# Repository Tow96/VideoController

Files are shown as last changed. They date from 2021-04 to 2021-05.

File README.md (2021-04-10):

# Video Controller Surface



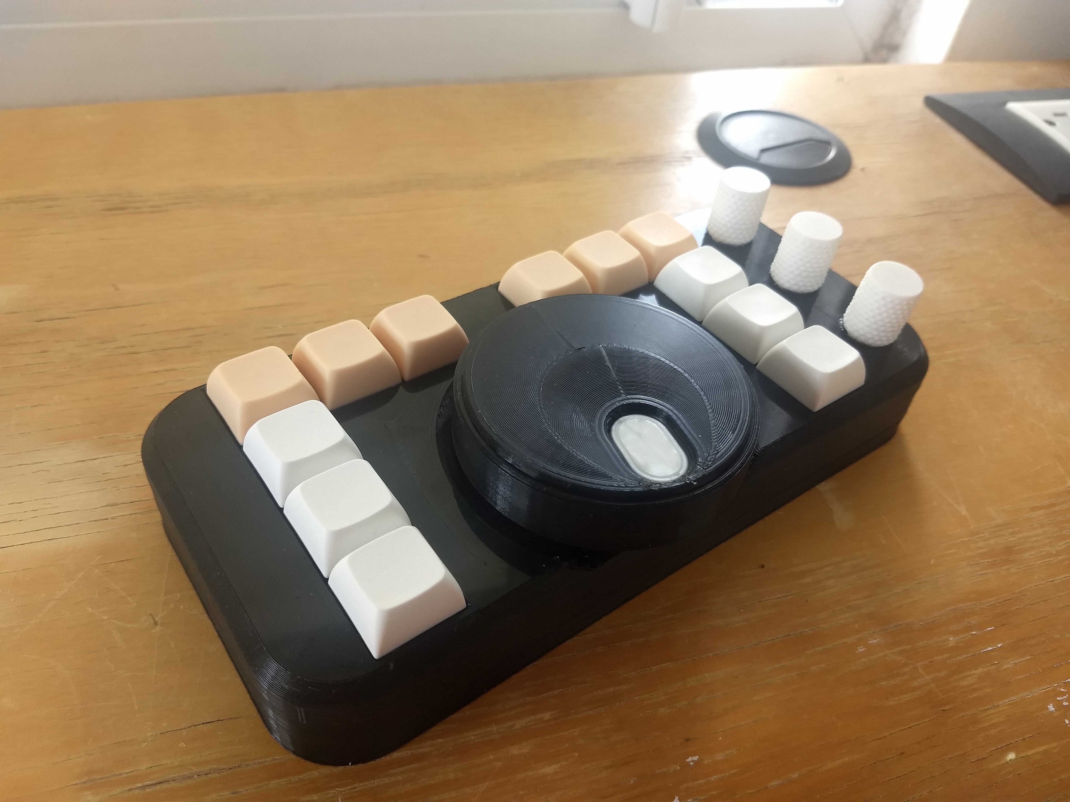
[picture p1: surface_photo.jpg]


Simple surface for video editing utilizing a Teensy 2.0 It's main purpose is to be utilized with the program 
Adobe Premiere Pro. However, thanks to the Teensy's HID interface, can also be utilized as a multipurpose 
Macro pad.

This surface has 12 buttons, a main central knob, and 3 secondary knobs. The four knobs also have buttons.

This project is heavily based by Zack-Freedman's [Big-Wheel](https://github.com/ZackFreedman/Big-Wheel) 
project.

## Repository structure
The repository is divided in four subfolders, each containing a different part of the project. Further 
documentation can be found inside these folders.

1. [**Assembly**](/Assembly) - This folder contains the files that make up the physical device. They are 
available in .SLDPRT and .STL formats.

2. [**Firmware**](/Firmware) - This folder contains the Firmware utilized by the device. It is built in 
platform.io and uses the [Teensyduino](https://www.pjrc.com/teensy/td_download.html) library.

3. [**Schematics**](/Schematics) - This folder contains the wiring diagrams, as well as the elements to 
manufacture a PCB for it.

4. [**Shortcut-Profiles**](/Shortcut-Profiles) - This folder contains .kys files for Adobe Premiere.

## Future improvements
The improvements are separated by category inside the documentation for each folder.

## Credits
- Jose Tow [[@Tow96](https://github.com/Tow96)]

Original idea from: Zack Freedman ([github](https://github.com/ZackFreedman), 
[youtube](https://www.youtube.com/channel/UCUW49KGPezggFi0PGyDvcvg))

## License
This project is licensed under [MIT license](/LICENSE) as I believe in open-source, specially when basing 
your project from another.

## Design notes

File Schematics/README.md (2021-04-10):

# Schematics
This folder contains the wiring diagrams, as well as the elements to manufacture a PCB for it.

The files are in EAGLE CAD format and also the gbr files are available to manufacture a PCB out of it.

**Warning:** The PCB has tolerances to fit inside the body of the device, and test prints have 
been made to check if the components fit. However a proper PCB hasn't been manufatured to test

## Teensy pins
The pins to which each component is wired can be changed on the [pins.h](../Firmware/src/pins.h) 
file. The default connections are:

Wire      | Pin
--------- | ---
Row A     | 5
Row B     | 6
Row C     | 16
Row D     | 15
Col 1     | 17
Col 2     | 18
Col 3     | 3
Col 4     | 4
TopKnob A | 8
TopKnob B | 7
MidKnob A | 10
MidKnob B | 9
BotKnob A | 13
BotKnob B | 14
Wheel A   | 11
Wheel B   | 12

## Hand soldering
The case is also designed to be hand soldered instead of using a pcb. Here is the name of each button and knob matching the schematics.

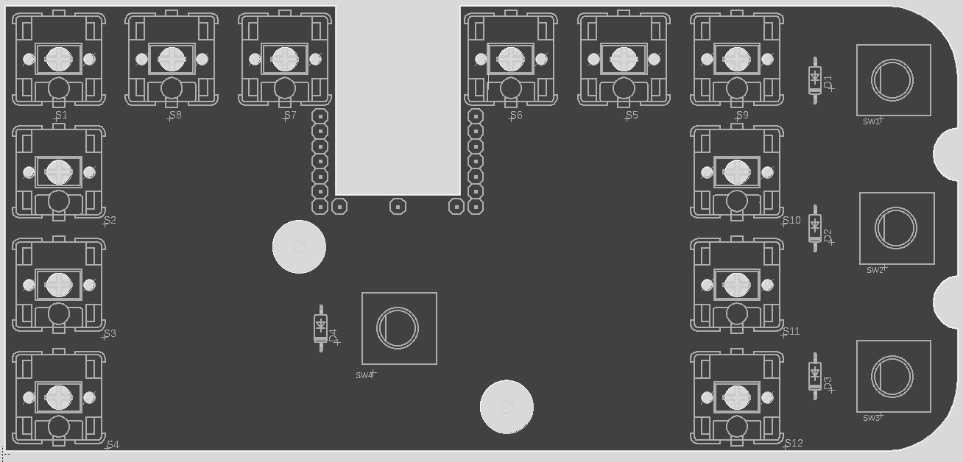
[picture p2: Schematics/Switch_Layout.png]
Layout


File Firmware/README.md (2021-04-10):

# Firmware
This folder contains the Firmware utilized by the device. It is built in 
platform.io and uses the [Teensyduino](https://www.pjrc.com/teensy/td_download.html) library.

## Build
To build the firmware, VsCode with platform.io is required. Building the firmware should 
install the required dependencies.

## Future improvements
- [ ] Add different actions depending of the speed the main knob is turned.

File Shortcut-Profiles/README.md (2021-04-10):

# Shortcut Profiles
This folder contains .kys files for Adobe Premiere. 

The reason for this is that the Teensy keyboard library utilizes the keys for the US keyboard instead of 
ASCII. The issue also applies in Adobe Premiere where depending on the layout of the keyboard, the mappings 
are changed. In order to combat this, .kys files for each keyboard shortcut are created. The intention of 
these files is to not interfere with the default profile.

## Currently supported layouts

- Latin American (LAA)

## Future improvements
- [ ] Add US (INTL) layout

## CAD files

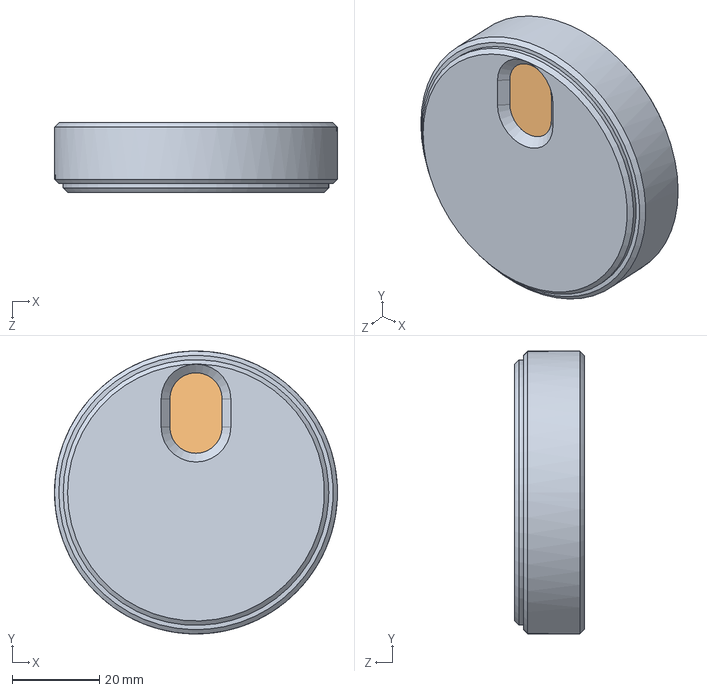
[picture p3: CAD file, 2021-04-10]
Assembly/Parts/01-Wheel/01-Wheel.SLDASM
65.0 x 65.0 x 16.0 mm
01-Body
02-Indent

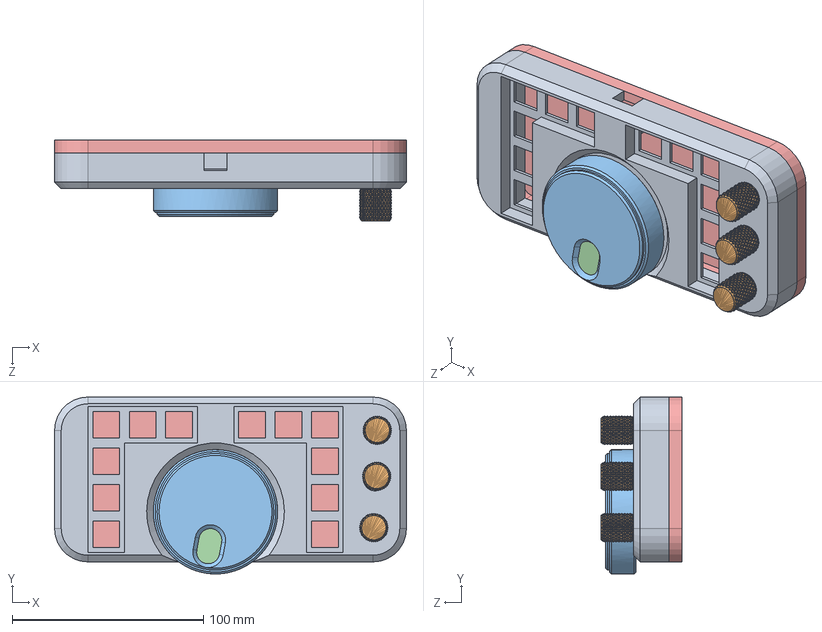
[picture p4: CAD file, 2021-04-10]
Assembly/Video_Controller.SLDASM
184.0 x 92.5 x 42.6 mm
00-Baseplate
02-Encoder_Knob x 3
01-Body
02-Indent
03-Backplate

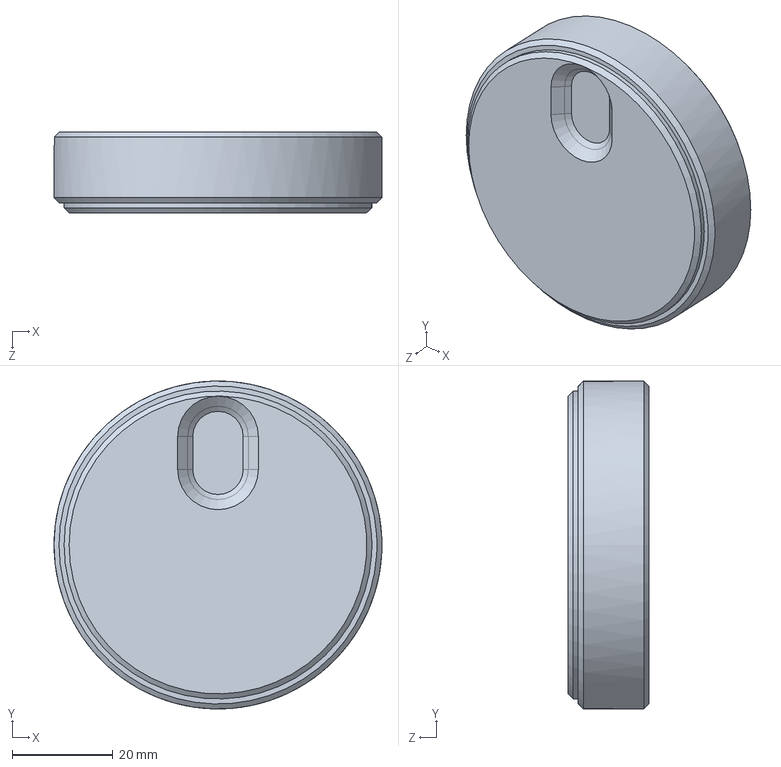
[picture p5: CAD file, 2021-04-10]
Assembly/Parts/01-Wheel/Parts/01-Body.SLDPRT
65.0 x 65.0 x 16.0 mm

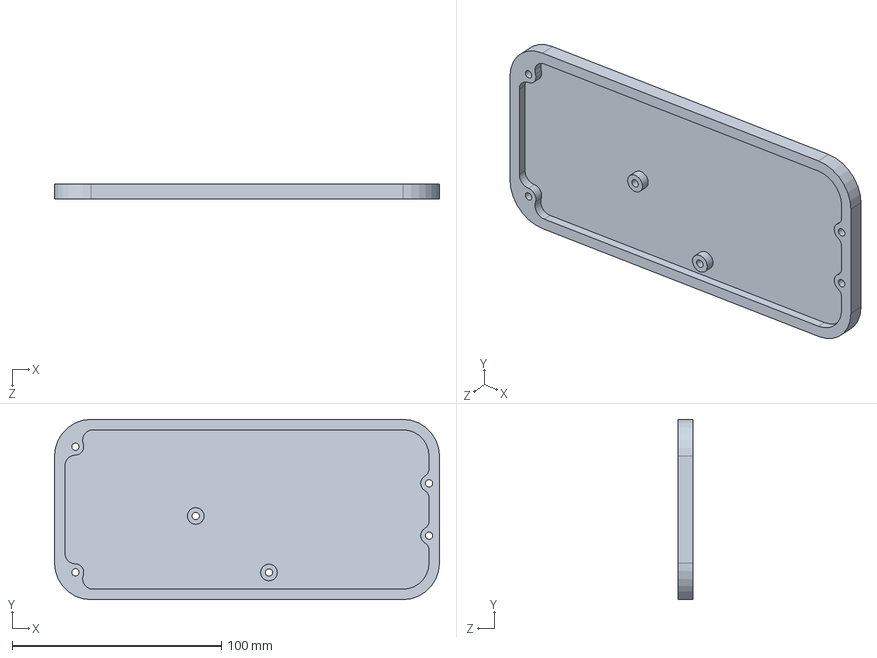
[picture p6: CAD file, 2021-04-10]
Assembly/Parts/03-Backplate.SLDPRT
184.0 x 86.2 x 7.00 mm

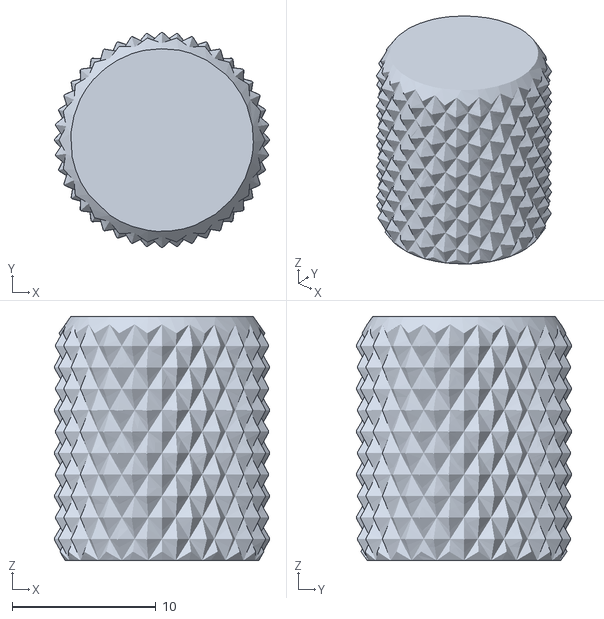
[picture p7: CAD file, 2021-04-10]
Assembly/STL/Video_Controller - 02-Encoder_Knob-2.STL
15.0 x 15.0 x 17.0

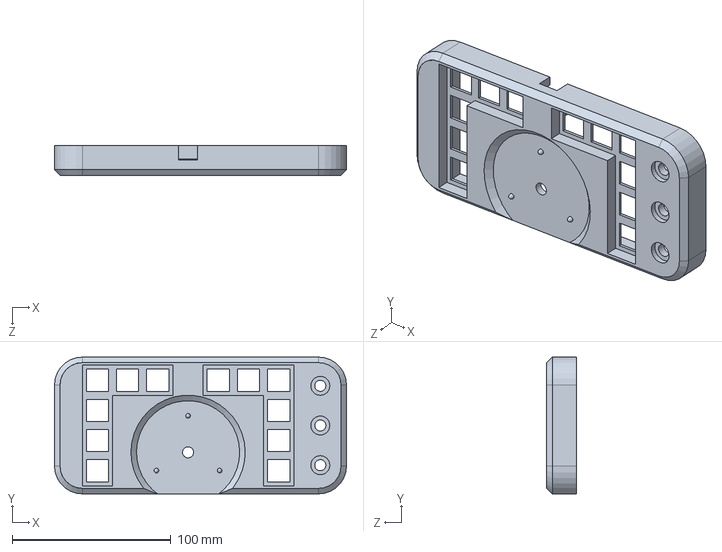
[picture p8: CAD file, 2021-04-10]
Assembly/Parts/00-Baseplate.SLDPRT
184.0 x 86.2 x 18.6 mm

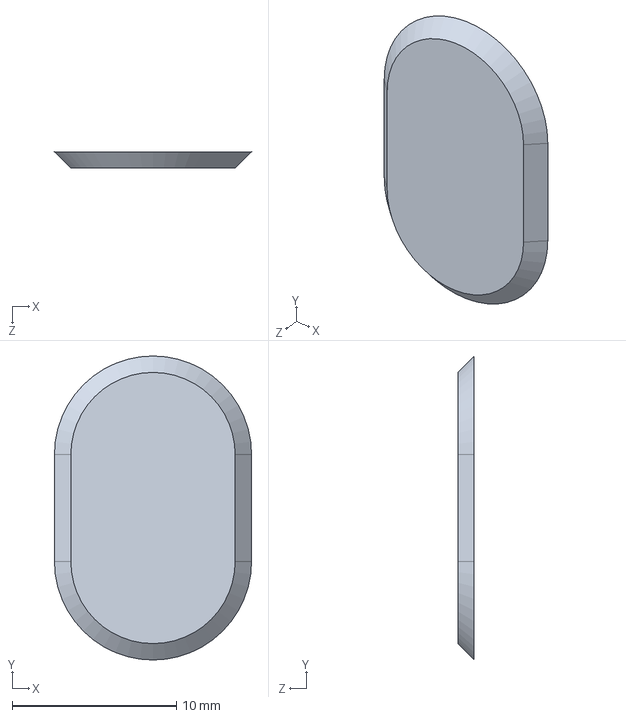
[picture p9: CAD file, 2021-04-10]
Assembly/Parts/01-Wheel/Parts/02-Indent.SLDPRT
12.0 x 18.5 x 1.00 mm

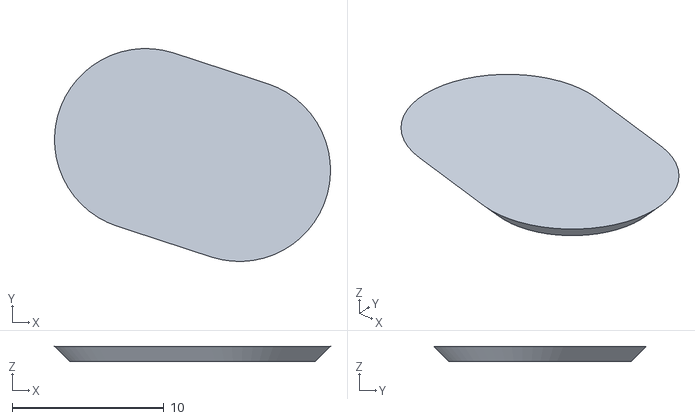
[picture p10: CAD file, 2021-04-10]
Assembly/STL/Video_Controller - 01-Wheel-1 02-Indent-1.STL
18.2 x 14.0 x 1.00

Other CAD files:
Assembly/STL/Video_Controller - 02-Encoder_Knob-1.STL
Assembly/Parts/02-Encoder_Knob.SLDPRT
Assembly/STL/Video_Controller - 00-Baseplate-1.STL
Assembly/STL/Video_Controller - 03-Backplate-1.STL
Assembly/STL/Video_Controller - 02-Encoder_Knob-3.STL
Assembly/STL/Video_Controller - 01-Wheel-1 01-Body-1.STL

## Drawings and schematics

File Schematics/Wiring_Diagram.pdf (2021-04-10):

# COL_1 COL_1

A

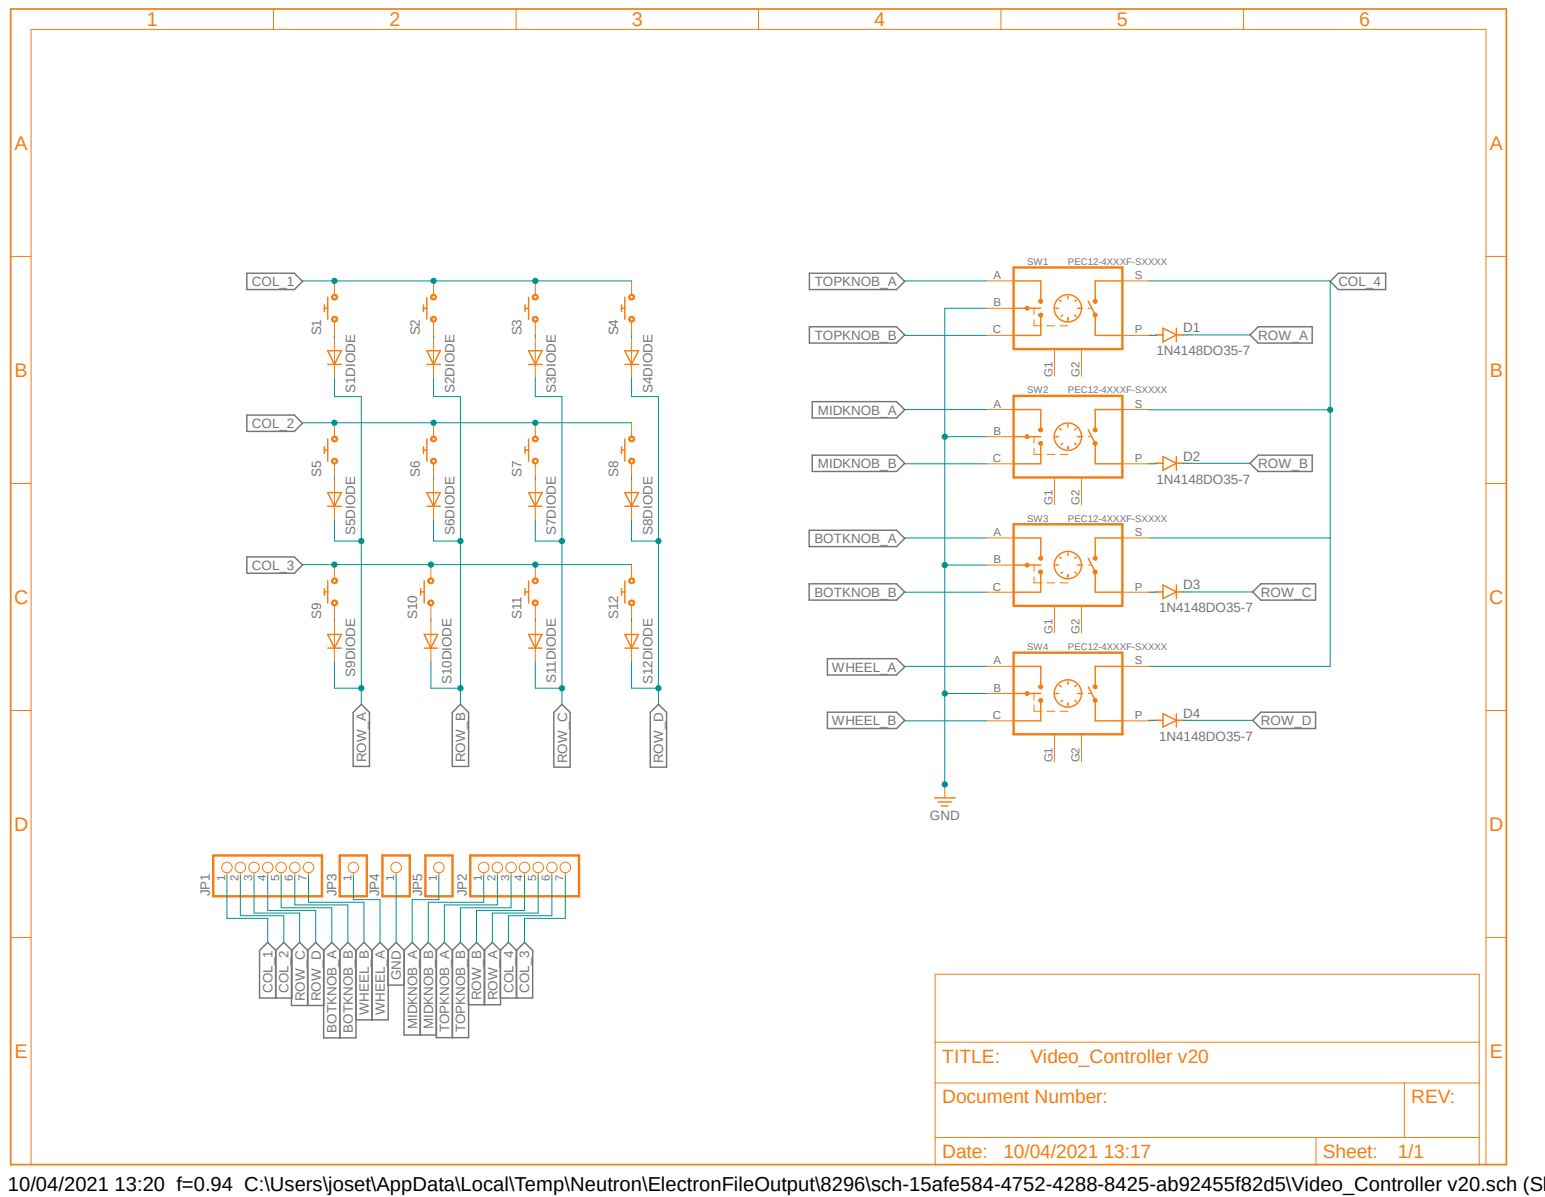
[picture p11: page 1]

Document Number: | REV:

Date: 10/04/2021 13:17 | Sheet: 1/1

10/04/2021 13:20 f=0.94 C:\Users\joset\AppData\Local\Temp\Neutron\ElectronFileOutput\8296\sch-15afe584-4752-4288-8425-ab92455f82d5\Video_Controller v20.sch (Sheet: 1/1)

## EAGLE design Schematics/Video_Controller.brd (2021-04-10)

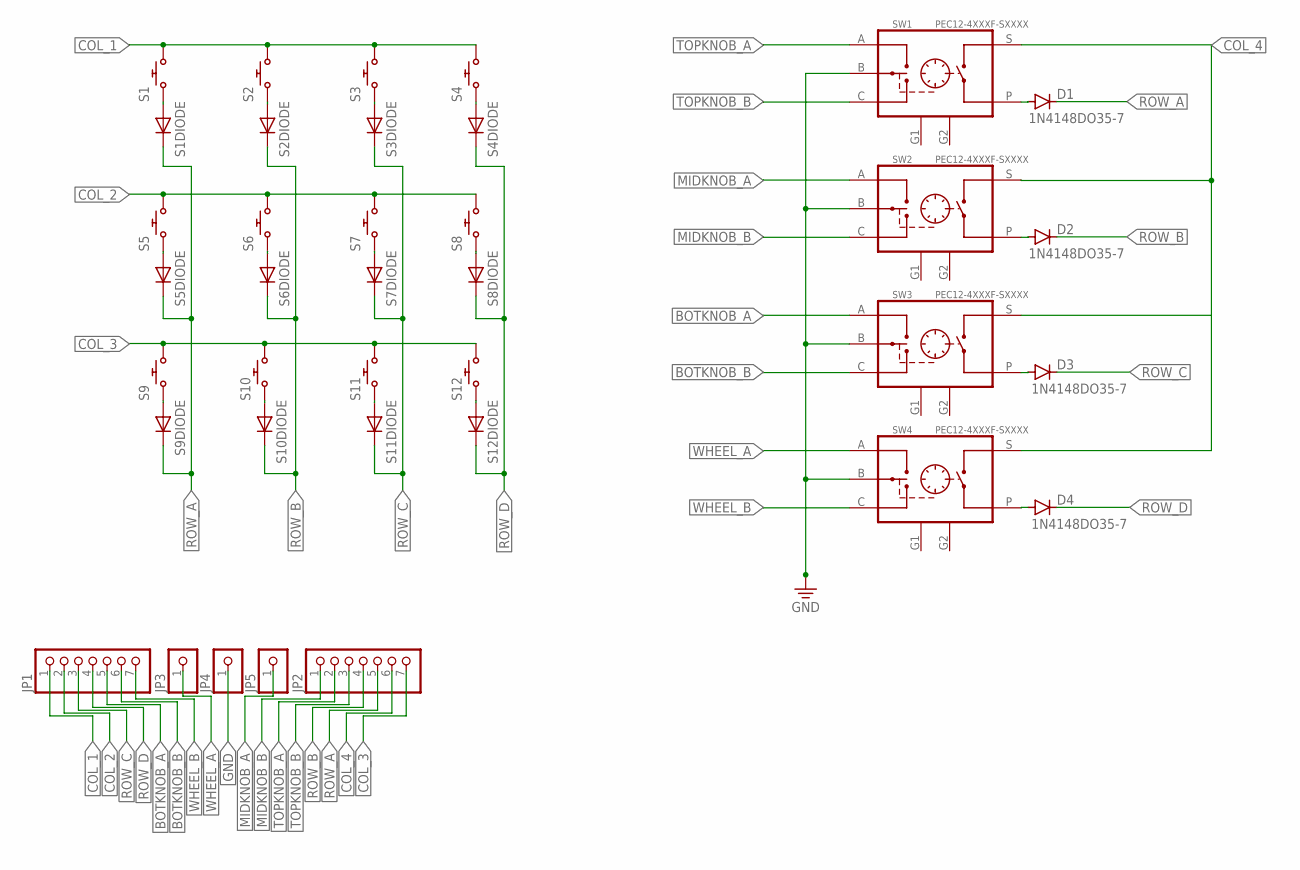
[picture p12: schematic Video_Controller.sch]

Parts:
D1, D2, D3, D4: 1N4148DO35-7; DO35-7
JP1, JP2: PINHD-1X7; 1X07
JP3, JP4, JP5: PINHD-1X1; 1X01
S1, S2, S3, S4, S5, S6, S7, S8, S9, S10, S11, S12: CHERY_MX_DIODE; CHERRY_MX_DIODE
SW1, SW2, SW3, SW4: PEC12-4XXXF-SXXXX; PEC12-4XXX

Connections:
BOTKNOB_A: JP1.5, SW3.A
BOTKNOB_B: JP1.6, SW3.C
COL_1: JP1.1, S1.S2 (2), S2.S2 (2), S3.S2 (2), S4.S2 (2)
COL_2: JP1.2, S5.S2 (2), S6.S2 (2), S7.S2 (2), S8.S2 (2)
COL_3: JP2.7, S9.S2 (2), S10.S2 (2), S11.S2 (2), S12.S2 (2)
COL_4: JP2.6, SW1.S
GND: JP4.1, SW1.B, SW2.B, SW3.B, SW4.B
MIDKNOB_A: JP5.1, SW2.A
MIDKNOB_B: JP2.1, SW2.C
unnamed: S1.D1 (A), S1.S1 (1)
unnamed: S2.D1 (A), S2.S1 (1)
unnamed: S3.D1 (A), S3.S1 (1)
unnamed: S4.D1 (A), S4.S1 (1)
unnamed: D1.A, SW1.P
unnamed: D2.A, SW2.P
unnamed: D3.A, SW3.P
unnamed: D4.A, SW4.P
unnamed: S5.D1 (A), S5.S1 (1)
unnamed: S6.D1 (A), S6.S1 (1)
unnamed: S7.D1 (A), S7.S1 (1)
unnamed: S8.D1 (A), S8.S1 (1)
unnamed: S9.D1 (A), S9.S1 (1)
unnamed: S11.D1 (A), S11.S1 (1)
unnamed: S10.D1 (A), S10.S1 (1)
unnamed: SW2.S, SW3.S, SW4.S
unnamed: S12.D1 (A), S12.S1 (1)
ROW_A: D1.C, JP2.5, S1.D2 (C), S5.D2 (C), S9.D2 (C)
ROW_B: D2.C, JP2.4, S2.D2 (C), S6.D2 (C), S10.D2 (C)
ROW_C: D3.C, JP1.3, S3.D2 (C), S7.D2 (C), S11.D2 (C)
ROW_D: D4.C, JP1.4, S4.D2 (C), S8.D2 (C), S12.D2 (C)
TOPKNOB_A: JP2.2, SW1.A
TOPKNOB_B: JP2.3, SW1.C
WHEEL_A: JP3.1, SW4.A
WHEEL_B: JP1.7, SW4.C

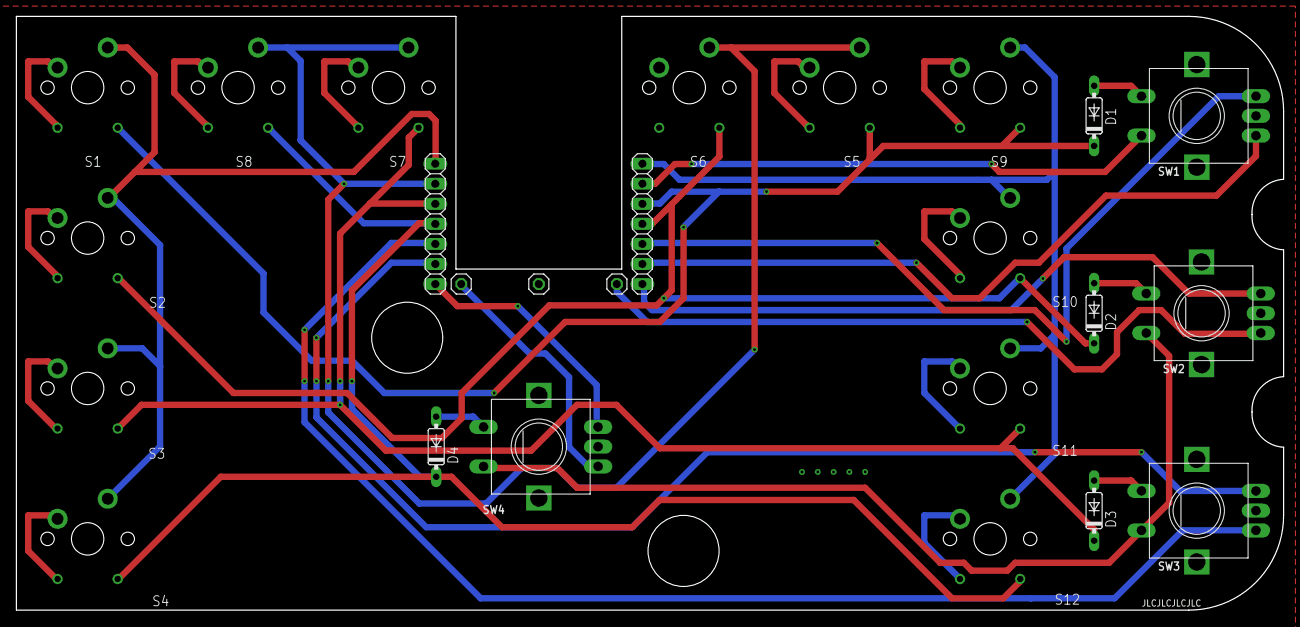
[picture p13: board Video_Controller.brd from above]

Board: 2 copper layers, 160.5 x 75.2 mm, 25 parts (0 on the bottom side), 34 nets.

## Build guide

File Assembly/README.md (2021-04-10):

# Assembly
This folder contains the files that make up the physical device. They are available in .SLDPRT and .STL 
formats.

The files are:

- Baseplate - The main body of the device, every component is mounted to this. It has holes to install 
M3x5x4 heat set inserts to it.

- Wheel - The knob for the main encoder, consists of two pieces to provide an accent to the build.

- Backplate - Plate to cover the electronics.

- Encoder Knob - Knurled knob by 
[Fukurami-san on Thingiverse](https://www.thingiverse.com/thing:4541677/) 

## Materials
The materials required to build the controller are the following:

Item                            | Qty
------------------------------- | ---
Baseplate                       | 1
Wheel                           | 1
Backplate                       | 1
Encoder Knob                    | 3
M3x5x4 heat set inserts         | 6
M3x10 screws                    | 6
Cherry mx compatible switch     | 12
Cherry mx compatible keycap     | 12
PEC12 compatible rotary encoder | 4
Teensy 2.0                      | 1
*Optional* [PCB](../Schematics) | 1

## Future improvements
- [ ] Add build guide
- [ ] Change the backplate to utilize lower profile screws.

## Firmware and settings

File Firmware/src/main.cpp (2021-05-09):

/*
 * Video Controller macro pad firmware
 * Copyright April 2021 José Tow
 * 
 * This code is designed to run on the following hardware: https://github.com/Tow96/VideoController
 * 
 * This code is heavily based in the project made by Zack Freedman:
 *   https://github.com/ZackFreedman/Big-Wheel
 *   https://www.youtube.com/watch?v=72a85tWOJVY
 */

#include <Arduino.h>
#include <HID.h>
#include <Keyboard.h>
#include <Encoder.h>

#include "configuration.h"

#include "pins.h"
// #include "actions.h"
#include "buttons.h"
#include "knobs.h"

// ActionQueue actionQueue;
Button buttonMatrix[16];
Knob* knobs[4] = {
  new Knob(topKnobA, topKnobB),
  new Knob(midKnobA, midKnobB),
  new Knob(botKnobA, botKnobB),
  new Knob(wheelA, wheelB)
};

void setup()
{
  #ifdef DEBUG
    Serial.begin(9600);
  #endif

  // Starts the keyboard
  Keyboard.begin();

  // Sets the keyboard matrix up
  for (int i = 0; i < 4; i++)
  {
    // Rows
    pinMode(rowPins[i], OUTPUT);
    digitalWrite(rowPins[i], HIGH);

    // Columns
    pinMode(colPins[i], INPUT_PULLUP);
  }
}

void loop()
{
  // Reads the keyboard matrix and stores it in the buttons
  for (int i = 0; i < 4; i++) {
     // Sets the row pin to Low to read each column
    digitalWrite(rowPins[i], LOW);

    // Reads each column
    for (int j = 0; j < 4; j++) {

        bool buttonState = !digitalRead(colPins[j]);

        int pos =  (j*4) + i;
        buttonMatrix[pos].setState(buttonState);

        #if defined(DEBUG) && defined(DEBUG_DUMP_MATRIX)
        if(buttonState) {
          Serial.print("Pressed key: ");
          Serial.print(j);
          Serial.print(",");
          Serial.println(i);
        }
        #endif
        
    }

    // Sets the row pin back to HIGH
    digitalWrite(rowPins[i], HIGH);
  }

  // Requests the debounced state of the buttons and if being pressed (rising edge) queues the correct action. 
  // Since this is a macro pad, no aditional inputs for the same key will be queued if left pressed.
  for (int i = 0; i < 16; i++) {
    int state = buttonMatrix[i].getState();

    if (state == BUTTON_RISINGEDGE) {
      #if defined(DEBUG) && defined(DEBUG_DUMP_ACTIONS)
        Serial.print("Queue action set for key: ");
        Serial.println(i);
      #endif

      // actionQueue.queueAction(buttonAssignments[i]);
    }
  }

  // Reads the knobs and if moved, queues the action
  for (int i = 0; i < 4; i++) {
    knobs[i]->read();

    int delta = knobs[i]->getDelta();

    if ( delta != 0 ) {

      #if defined(DEBUG) && defined(DEBUG_DUMP_KNOBPOSITIONS)
        Serial.print("Knob ");
        Serial.print(i);
        Serial.print(" --> ");
      #endif

      // CW movement
      if ( delta > 0 ) {
        #if defined(DEBUG) && defined(DEBUG_DUMP_KNOBPOSITIONS)
          Serial.println("CW");
        #endif

      //   // Enqueues the respective action
      //   switch (i) {
      //     case 0:
      //       actionQueue.queueAction(topKnobAssignments[0]);
      //       break;
      //     case 1:
      //       actionQueue.queueAction(midKnobAssignments[0]);
      //       break;
      //     case 2:
      //       actionQueue.queueAction(botKnobAssignments[0]);
      //       break;
      //     case 3:
      //       actionQueue.queueAction(wheelAssignments[0]);
      //       break;
      //     default:
      //       break;
      //   }
      }

      // CCW movement
      if ( delta < 0 ) {
        #if defined(DEBUG) && defined(DEBUG_DUMP_KNOBPOSITIONS)
          Serial.println("CCW");
        #endif

        // Enqueues the respective action
        // switch (i) {
        //   case 0:
        //     actionQueue.queueAction(topKnobAssignments[1]);
        //     break;
        //   case 1:
        //     actionQueue.queueAction(midKnobAssignments[1]);
        //     break;
        //   case 2:
        //     actionQueue.queueAction(botKnobAssignments[1]);
        //     break;
        //   case 3:
        //     actionQueue.queueAction(wheelAssignments[1]);
        //     break;
        //   default:
        //     break;
        // }
      }

    }

  }

  // // Executes the queued actions
  // actionQueue.executeActions();
}

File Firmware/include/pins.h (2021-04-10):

/** pins.h
 * Copyright (c) Jose Tow, 2021
 * Header file that contains the classes utilized to contain which pins are
 * connected to each component for the button matrix and the knobs
 */

#ifndef PINS_H_
  #define PINS_H_
  
  // Knobs
  #define topKnobA 8
  #define topKnobB 7
  #define midKnobA 10
  #define midKnobB 9
  #define botKnobA 13
  #define botKnobB 14
  #define wheelA   11
  #define wheelB   12

  const byte allKnobPins[] = 
  {
    topKnobA, topKnobB,
    midKnobA, midKnobB,
    botKnobA, botKnobB,
    wheelA, wheelB
  };

  // Matrix
  #define rowA 5
  #define rowB 6
  #define rowC 16
  #define rowD 15

  #define col1 17
  #define col2 18
  #define col3 3
  #define col4 4

  const byte rowPins[] = {rowA, rowB, rowC, rowD};
  const byte colPins[] = {col1, col2, col3, col4};

#endif

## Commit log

2021-04-10 v1.0
    Version 1.0 of the Video Controller
    [00-Baseplate.SLDPRT, 01-Body.SLDPRT, 01-Wheel.SLDASM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]
2021-05-09 Moved the header files to /include
    [configuration.h]
2021-05-09 Updated the code to arduino
    The Action queue is missing
    [main.cpp]

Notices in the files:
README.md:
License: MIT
